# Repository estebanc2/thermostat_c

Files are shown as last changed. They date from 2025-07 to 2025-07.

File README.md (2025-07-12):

# Thermostat

## Summary

This repository describes how to build a "thermostat" to make yogurt keeping temp around 40 °C turning on and off a heater source.

This is an open-source software and hardware project. The circuit diagram and board layout design, the programs in C for the ESP 8266 microcontroller are made available under the GPLv3 license. See the file LICENSE.txt in the same directory along with this file.

## Hardware

The hardware design is quite simple; just what the Espressif 8266 module needs to operate:

- 5V @ 200mA power supply
- 3.3V regulator
- One 220VAC @ 6A relays to control the load(s)
- DS18B20 temperature sensor(HW/DS18B20.pdf)

The following pictures show the schematics, boards, and switches with all their elements.

The HW folder in this repository contains documents needed to order boards from [JLCPCB](https://jlcpcb.com/) and Kikad projects for simple and double switches.

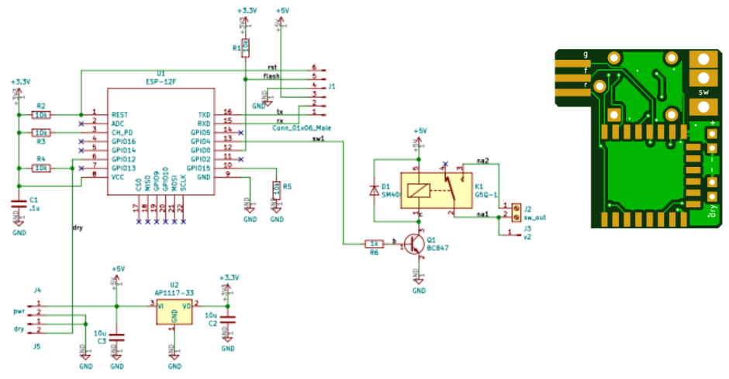
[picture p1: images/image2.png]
image_tooltip


## Software

There is a simple periodic task that keep the switch on until 41°C, the upper side of the histeresis and turn it on again under 39°C, the lowwer side of the histeresis.
To read the temperature I used other open source project: [one_wire](https://github.com/estebanc2/one_wire)

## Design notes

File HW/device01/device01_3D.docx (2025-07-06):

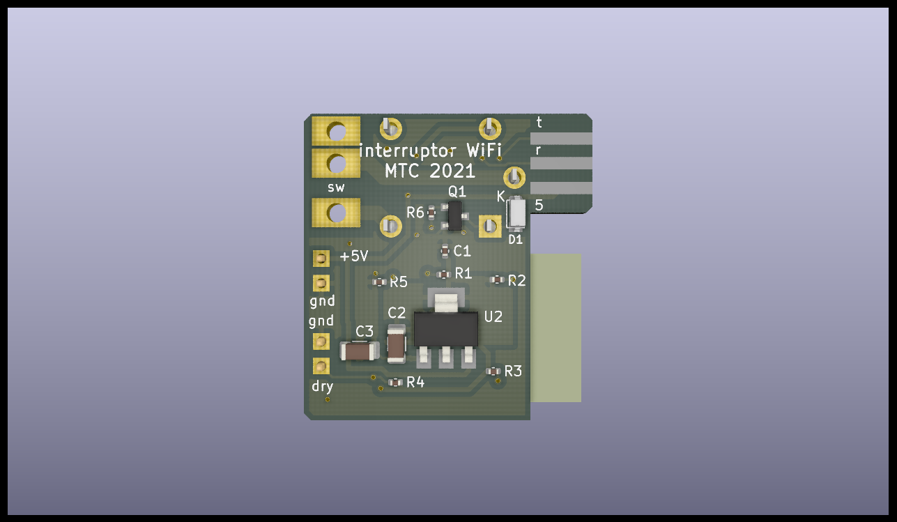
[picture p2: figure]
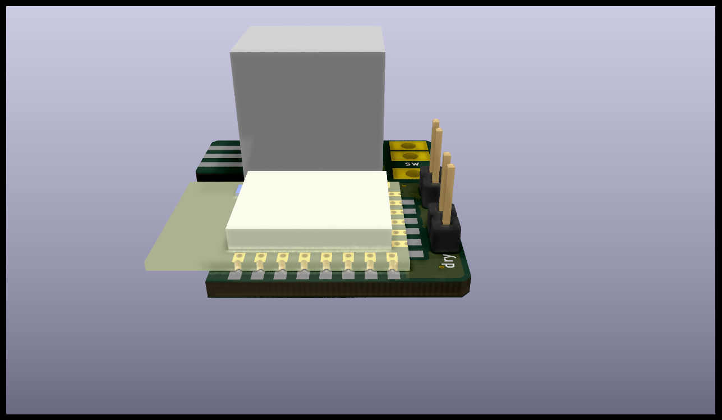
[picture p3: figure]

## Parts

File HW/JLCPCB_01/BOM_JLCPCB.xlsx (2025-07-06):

Comment | Designator | Footprint | LCSC part Number
100nF | C1 | 0402 | C60474
10uF | C2,C3 | 1206 | C92765
SM4007PL | D1 | SOD-123FL | C64898
10K | R1,R2,R3,R4,R5 | 0402 | C60489
1K | R6 | 0402 | C105637
AP1117-33 | U2 | SOT-223 | C173386
BC847 | Q1 | SOT-23 | C57668

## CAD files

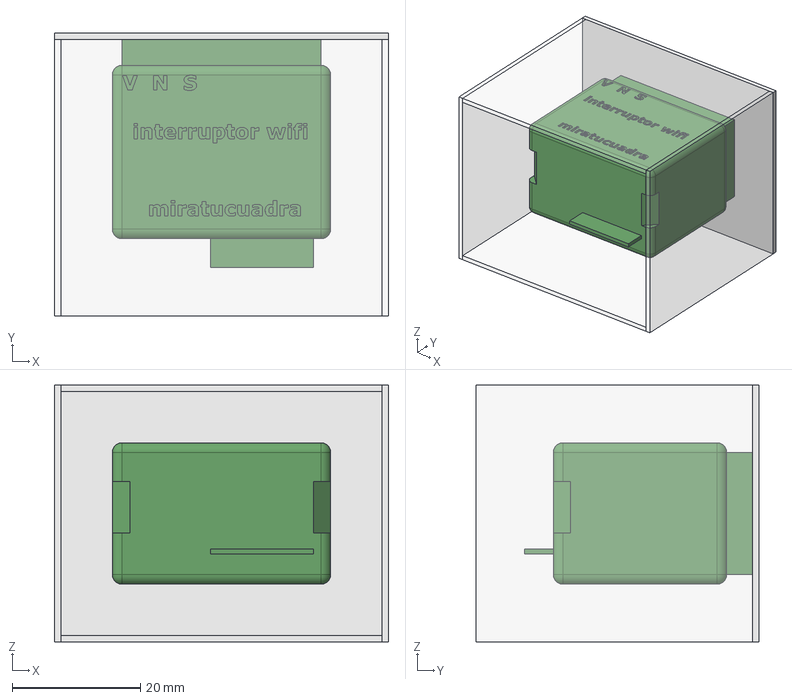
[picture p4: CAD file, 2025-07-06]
HW/device01/device01_molde.FCStd
52.0 x 44.0 x 40.0 mm
molde
base
frente
derecha
atras
izquierda

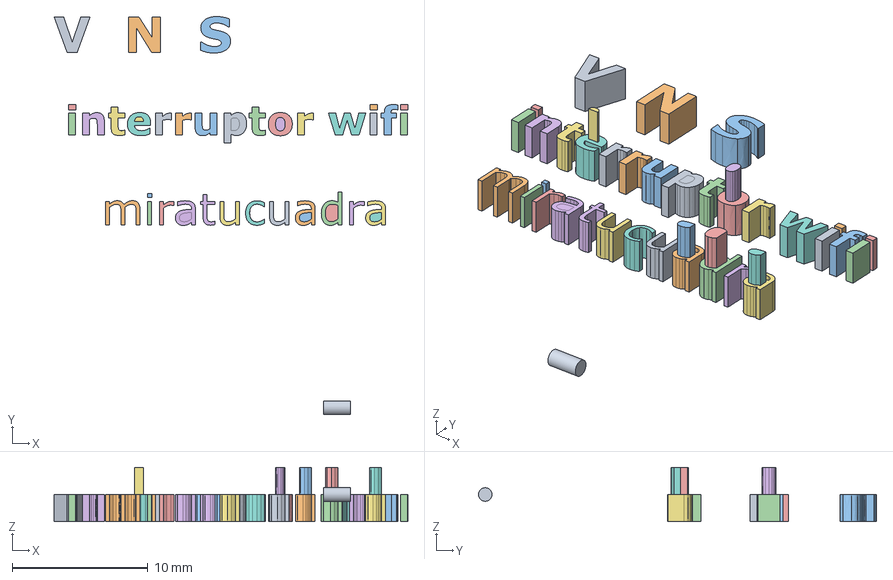
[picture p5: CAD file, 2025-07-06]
HW/device01/device01_funda_reprog.FCStd
26.1 x 29.3 x 4.00 mm

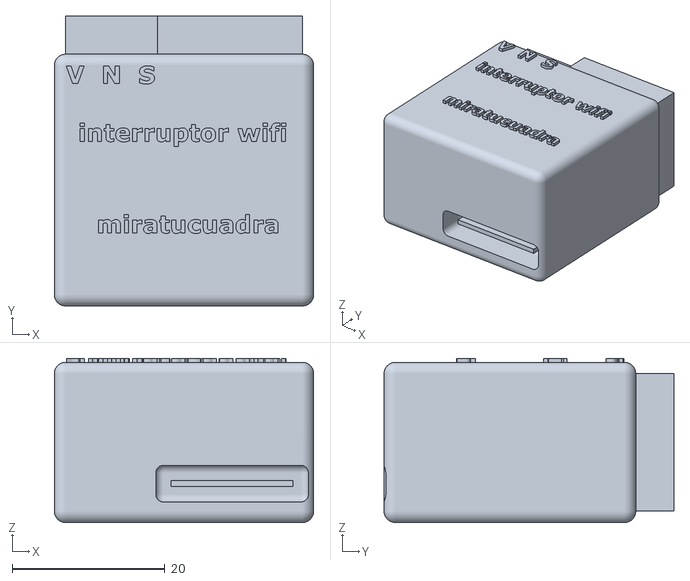
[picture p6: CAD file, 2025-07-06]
HW/device01/device01_para_colar-molde.stl
34.0 x 38.0 x 21.5

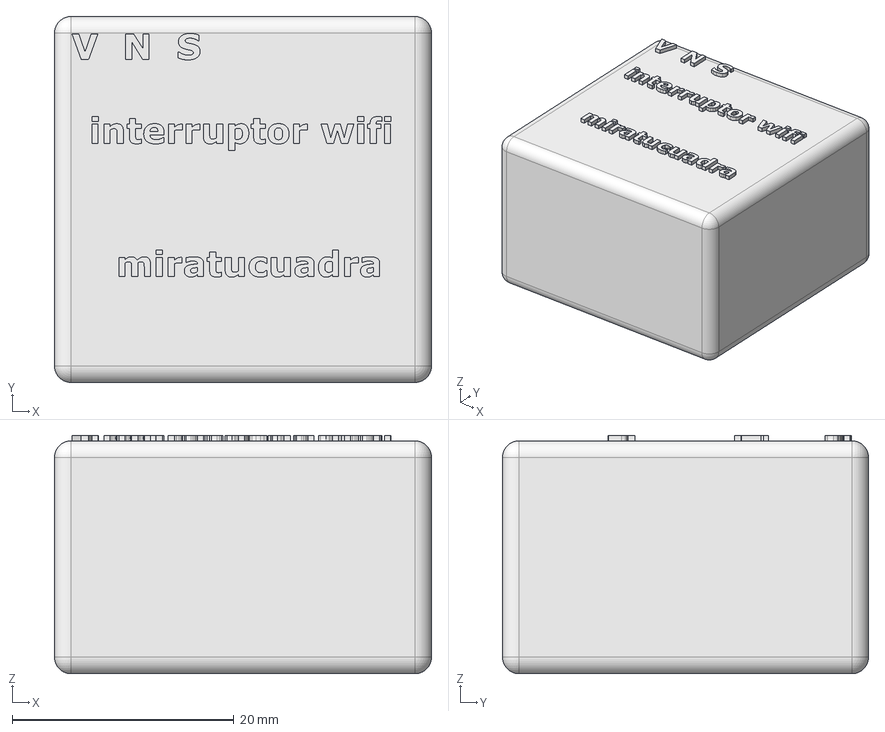
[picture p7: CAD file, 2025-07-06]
HW/device01/device01_carcaza sola.FCStd
34.0 x 33.0 x 21.5 mm

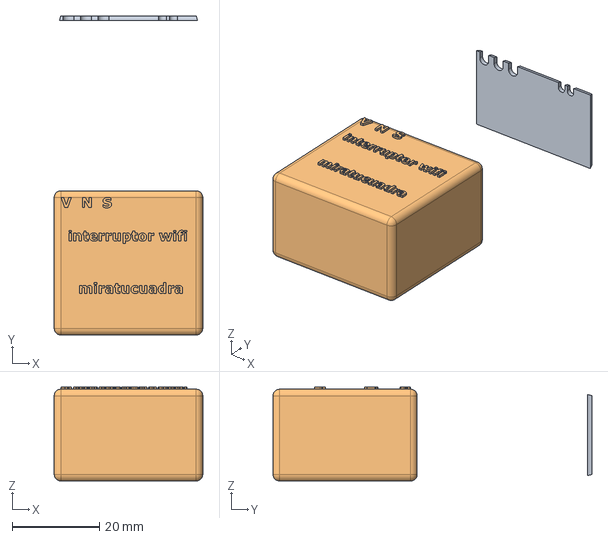
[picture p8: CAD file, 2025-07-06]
HW/device01/device01_funda_hueca.FCStd
34.0 x 73.0 x 21.5 mm
tapa
carcaza

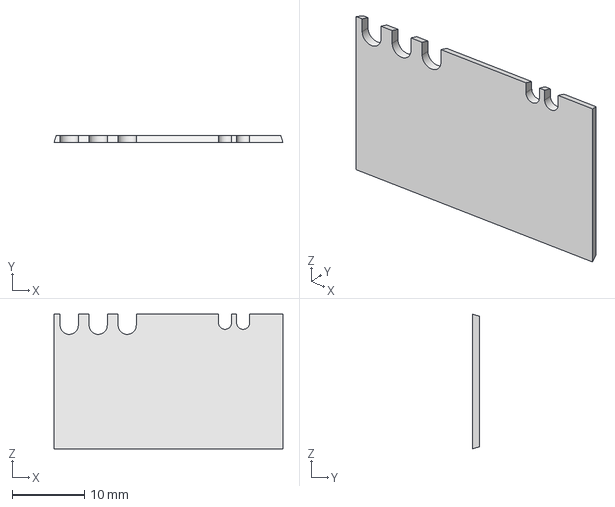
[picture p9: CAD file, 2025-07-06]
HW/device01/tapa.FCStd
31.6 x 1.00 x 18.6 mm

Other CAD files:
HW/device01/tapa.stl

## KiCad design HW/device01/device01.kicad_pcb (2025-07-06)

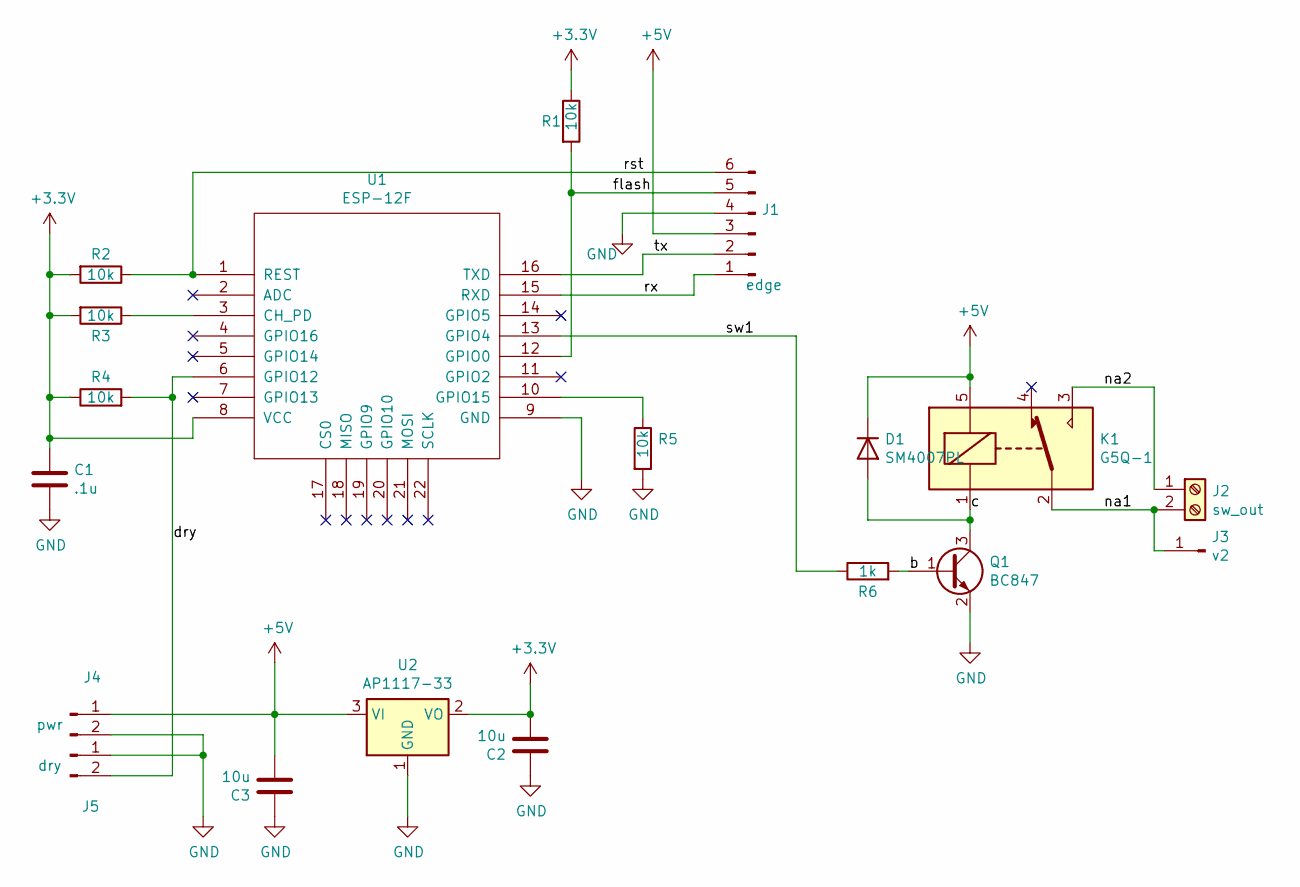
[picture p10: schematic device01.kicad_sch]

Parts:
C1: .1u; C_0402_1005Metric
C2, C3: 10u; C_1206_3216Metric
D1: SM4007PL
J1: edge; edge6
J2: sw_out; TerminalBlock_RND_205-00232_1x02_P5.08mm_Horizontal
J3: v2; 1wirehole
J4: pwr; PinHeader_1x02_P2.54mm_Vertical
J5: dry; PinHeader_1x02_P2.54mm_Vertical
K1: G5Q-1; Relay_SPDT_Omron-G5Q-1
Q1: BC847; SOT-23
R1, R2, R3, R4, R5: 10k; C_0402_1005Metric
R6: 1k; C_0402_1005Metric
U1: ESP-12F; ESP-12E_SMD
U2: AP1117-33; SOT-223-3_TabPin2

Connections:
+3V3: C1.1, C2.2, R1.1, R2.2, R3.2, R4.1, U1.8 (VCC), U2.2 (VO)
+5V: C3.2, D1.1 (K), J1.3, J4.1, K1.5, U2.3 (VI)
/b: Q1.1 (B), R6.2
/c: D1.2 (A), K1.1, Q1.3 (C)
/dry: J5.2, R4.2, U1.6 (GPIO12)
/flash: J1.5, R1.2, U1.12 (GPIO0)
/na1: J2.2, J3.1, K1.2
/na2: J2.1, K1.3
/rst: J1.6, R2.1, U1.1 (REST)
/rx: J1.1, U1.15 (RXD)
/sw1: R6.1, U1.13 (GPIO4)
/tx: J1.2, U1.16 (TXD)
GND: C1.2, C2.1, C3.1, J1.4, J4.2, J5.1, Q1.2 (E), R5.2, U1.9 (GND), U2.1 (GND)
unnamed: R3.1, U1.3 (CH_PD)
unnamed: R5.1, U1.10 (GPIO15)

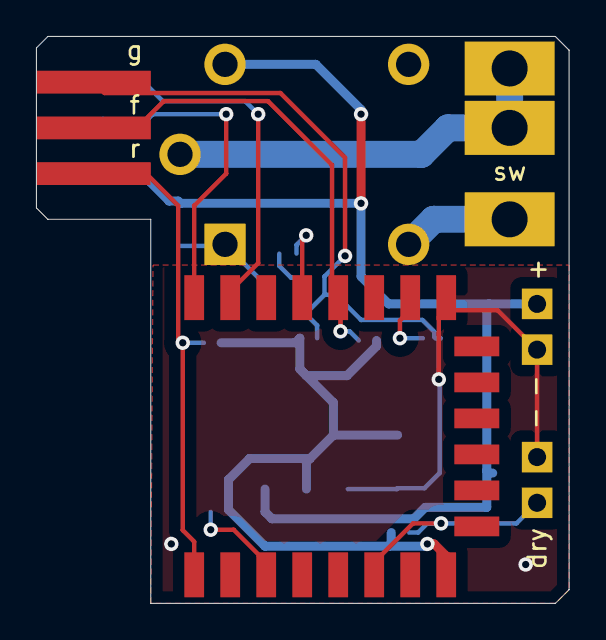
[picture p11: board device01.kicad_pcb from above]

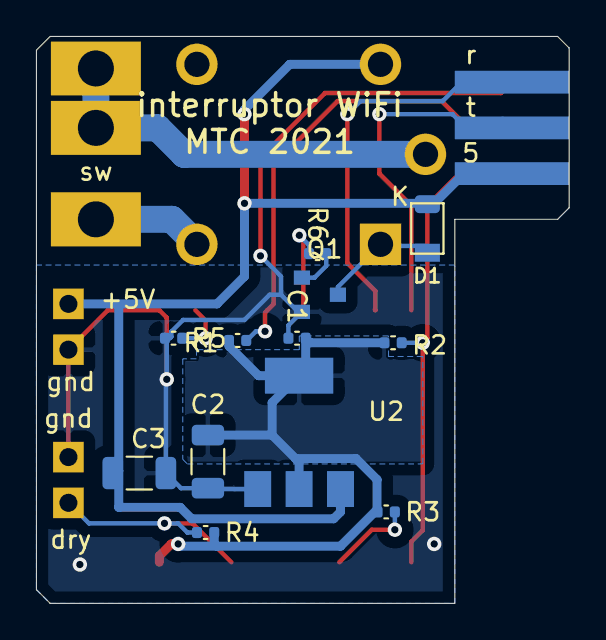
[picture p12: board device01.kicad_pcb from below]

Board: 2 copper layers, 29.6 x 31.5 mm, 19 parts (13 on the bottom side), 15 nets.

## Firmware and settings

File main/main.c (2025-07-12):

#include "ds18b20.h"

// GPIO assigment
#define SWITCH_OUTPUT 4
#define LED_OUTPUT 2
#define UNUSED_1_OUTPUT 5
#define UNUSED_2_OUTPUT 13
#define UNUSED_3_OUTPUT 14
#define UNUSED_4_OUTPUT 16
#define OUTPUT_PIN_SELECT ((1ULL << SWITCH_OUTPUT) | (1ULL << LED_OUTPUT) | (1ULL << UNUSED_1_OUTPUT) | (1ULL << UNUSED_2_OUTPUT) | (1ULL << UNUSED_3_OUTPUT) | (1ULL << UNUSED_4_OUTPUT))
//histeresis
#define TEMP_LOW_X_10 390
#define TEMP_HIGHT_X_10 410

static const char *TAG = "MAIN";

static uint64_t sonda[] = {
    0
};
static size_t sonda_size = sizeof(sonda) / sizeof(sonda[0]);

static void temp_check_task(void *arg){
    gpio_config_t io_conf;
    io_conf.intr_type = GPIO_INTR_DISABLE;    // disable interrupt
    io_conf.mode = GPIO_MODE_OUTPUT;          // set as output mode
    io_conf.pin_bit_mask = OUTPUT_PIN_SELECT; // bit mask of the pins that you want to set,e.g.GPIO15/16
    io_conf.pull_down_en = GPIO_PULLDOWN_DISABLE;                 // disable pull-down mode
    io_conf.pull_up_en = GPIO_PULLUP_DISABLE;                   // disable pull-up mode
    gpio_config(&io_conf); 
    set_gpio(12);
    int16_t temp[sonda_size];
    while (1){
        if( get_temperature (sonda, sonda_size, temp) == ESP_OK){
            for (uint8_t i = 0; i<(sonda_size); i++) {
                ESP_LOGI(TAG,"current sensor %d temperature x 10 = %d", i + 1, temp[i]);
            }
        } else {    
            ESP_LOGW(TAG,"no DS18B20 detected");
        }
        if(temp[0] < TEMP_LOW_X_10){
            gpio_set_level(SWITCH_OUTPUT, 1); // se prende
            gpio_set_level(LED_OUTPUT, 0); // se prende
        }
        else if (temp[0] > TEMP_HIGHT_X_10){
            gpio_set_level(SWITCH_OUTPUT, 0); //se apaga
            gpio_set_level(LED_OUTPUT, 1); // se apaga
        }
        vTaskDelay(1000 / portTICK_RATE_MS);
        gpio_set_level(LED_OUTPUT, 0); // se prende
        vTaskDelay(1000 / portTICK_RATE_MS);
    }
}
void app_main()
{
    xTaskCreate(temp_check_task, "temp_check_task", 2048, NULL, 20, NULL); 
}

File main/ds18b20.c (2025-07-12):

#include "ds18b20.h"

// ROM commands
#define MATCH_ROM 0x55
#define SKIP_ROM 0xCC
#define READ_ROM 0x33
//Function commands
#define CONVERT_T 0x44
#define READ_SCRATCH 0xBE
//1 wire times
#define MASTER_RESET_PULSE_DURATION 480 // Reset time high. Reset time low.
#define RESPONSE_MAX_DURATION 60        // Presence detect high.
#define PRESENCE_PULSE_MAX_DURATION 240 // Presence detect low.
#define RECOVERY_DURATION 1             // Bus recovery time.
#define TIME_SLOT_START_DURATION 1      // Time slot start.
#define TIME_SLOT_DURATION 80           // Time slot.
#define VALID_DATA_DURATION 15          // Valid data duration.

#ifdef CONFIG_IDF_TARGET_ESP8266
#define esp_delay_us(x) os_delay_us(x)
#else
#define esp_delay_us(x) esp_rom_delay_us(x)
#endif

static uint8_t pin;

esp_err_t set_gpio(uint8_t gpio)
{
    pin = gpio;
    gpio_config_t config;
    config.intr_type = GPIO_INTR_DISABLE;
    config.mode = GPIO_MODE_INPUT;
    config.pin_bit_mask = (1ULL << pin);
    config.pull_down_en = GPIO_PULLDOWN_DISABLE;
    config.pull_up_en = GPIO_PULLUP_ENABLE;
    if (gpio_config(&config) != ESP_OK)
    {
        return ESP_ERR_INVALID_ARG;
    }
    return ESP_OK;
}

static esp_err_t initialize (){
    gpio_set_direction(pin, GPIO_MODE_OUTPUT);
    gpio_set_level(pin, 0);
    esp_delay_us(MASTER_RESET_PULSE_DURATION);
    gpio_set_direction(pin, GPIO_MODE_INPUT);
    esp_delay_us(RECOVERY_DURATION);
    uint8_t response_time = 0;
    while (gpio_get_level(pin) == 1)
    {
        if (response_time > RESPONSE_MAX_DURATION)
        {
            return ESP_ERR_TIMEOUT;
        }
        ++response_time;
        esp_delay_us(1);
    }
    uint8_t presence_time = 0;
    while (gpio_get_level(pin) == 0)
    {
        if (presence_time > PRESENCE_PULSE_MAX_DURATION)
        {
            return ESP_ERR_TIMEOUT;
        }
        ++presence_time;
        esp_delay_us(1);
    }
    esp_delay_us(MASTER_RESET_PULSE_DURATION - response_time - presence_time);
    return ESP_OK;
}

static uint8_t read_1_bit(void)
{
    gpio_set_direction(pin, GPIO_MODE_OUTPUT);
    gpio_set_level(pin, 0);
    esp_delay_us(TIME_SLOT_START_DURATION);
    gpio_set_direction(pin, GPIO_MODE_INPUT);
    esp_delay_us(VALID_DATA_DURATION - TIME_SLOT_START_DURATION);
    uint8_t bit = gpio_get_level(pin);
    esp_delay_us(TIME_SLOT_DURATION - RECOVERY_DURATION - VALID_DATA_DURATION);
    return bit;
}

static void send_1_bit(const uint8_t bit)
{
    gpio_set_direction(pin, GPIO_MODE_OUTPUT);
    gpio_set_level(pin, 0);
    if (bit == 0)
    {
        esp_delay_us(58);//TIME_SLOT_DURATION);
        gpio_set_direction(pin, GPIO_MODE_INPUT);
        esp_delay_us(RECOVERY_DURATION);
    }
    else
    {
        esp_delay_us(TIME_SLOT_START_DURATION);
        gpio_set_direction(pin, GPIO_MODE_INPUT);
        esp_delay_us(TIME_SLOT_DURATION);
    }
}

static void send_1_byte (uint8_t byte){
    for (uint8_t i = 0; i < 8; ++i){
        send_1_bit(byte & 1);
        byte >>= 1;
    }
}

static uint8_t read_1_byte (void){
    uint8_t byte = 0;
    for (uint8_t i = 0; i < 8; ++i)
    {
        byte >>= 1;
        if (read_1_bit() != 0)
        {
            byte |= 0x80;
        }
    }
    return byte;
}

static uint8_t compute_crc8(const uint8_t *data, uint8_t len) {
    uint8_t crc = 0;
    uint8_t i, j;
    for (i = 0; i < len; i++) {
        crc ^= data[i];
        for (j = 0; j < 8; j++) {
            if (crc & 0x01) {
                crc = (crc >> 1) ^ 0x8C;
            } else {
                crc >>= 1;
            }
        }
    }
    return crc;
}

static esp_err_t crc_check (uint8_t *data, size_t len){
    uint8_t calculated_crc = compute_crc8((const uint8_t *)data, len-1);
    if (calculated_crc == data[len-1]){
        return ESP_OK;
    }else{
        return ESP_ERR_INVALID_CRC;
    }
}

esp_err_t get_temperature(const uint64_t *sonda, size_t sondas, int16_t *temp){
    if (initialize() != ESP_OK){
        return ESP_ERR_NOT_FOUND;
    }
    send_1_byte(SKIP_ROM);
    send_1_byte(CONVERT_T);
    vTaskDelay(750 / portTICK_PERIOD_MS);
    for (size_t i = 0; i < sondas; i++) {
        if (initialize() != ESP_OK){
            if (temp) temp[i] = -800; //ESP_ERR_NOT_FOUND; 
        } else {
            if (sonda[0] != 0) { 
                send_1_byte(MATCH_ROM);
                uint64_t pos = 0;
                for (uint8_t k = 0; k < 64; k++){
                     pos = (uint64_t)1 << k;
                    if ((sonda[i] & pos) == 0){
                        send_1_bit(0);
                    } else {
                        send_1_bit(1);
                        }
                }
            } else {
                send_1_byte(SKIP_ROM);
            }
            send_1_byte(READ_SCRATCH);
            rx_t rx = {0};
            for (uint8_t j = 0; j < 9; ++j)
            {
                rx.b[j] = read_1_byte();
            }
            if (crc_check(rx.b, 9) != ESP_OK){
                if (temp) temp[i] = -900;//ESP_ERR_INVALID_CRC
            } else{
                if (temp) temp[i] = (10 * (int16_t)((rx.b[1] << 8) | rx.b[0]))/ 16;
            }
        }
    }
    return ESP_OK;
}

esp_err_t get_rom(uint8_t pin, const uint64_t * rom){
    if (set_gpio(pin) != ESP_OK){
        return ESP_ERR_INVALID_ARG;
    }
    if (initialize() != ESP_OK){
        return ESP_ERR_NOT_FOUND; 
    }
    send_1_byte(READ_ROM);
    uint8_t rx[8] = {0};
    for (uint8_t i = 0; i < 8; i++){
        rx[i] = read_1_byte();
    }
    if (crc_check(rx, 8) != ESP_OK){
        return ESP_ERR_INVALID_CRC; 
    }
    uint64_t code = 0;
    for (int i = 0; i < 8; i++) {
        code |= ((uint64_t)rx[i]) << (8 * i);
    }
    if (rom) {
        *((uint64_t*)rom) = code;
    }
    return ESP_OK;
}
